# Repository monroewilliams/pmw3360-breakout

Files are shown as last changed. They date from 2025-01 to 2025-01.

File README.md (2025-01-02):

# Notes on this fork

I created this fork of jfedor2's excellent pmw3360-breakout board because I wanted a breakout that would better serve my particular needs.

Specifically, I wanted it to fit the existing plastics of [my trackball design](https://github.com/monroewilliams/trackball), which means having roughly the same dimensions and mounting hole locations as the ones I originally sourced from MrJohnK on Tindie [here](https://www.tindie.com/products/jkicklighter/pmw3360-motion-sensor/) (that one has been discontinued, but there are similar ones available from other sellers on Tindie).

Instead of the 2.54mm pitch pin header, also I wanted it to have a JST-SH (1.0mm pitch) connector with a regularized pinout based on [Pmod type 2](https://en.wikipedia.org/wiki/Pmod_Interface) so I can easily assemble it using compact off-the-shelf cables.

Since I don't need level-shifters (I'm using it with microcontrollers that already have compatible 3.3v logic), this breakout seemed like the perfect starting point. 

Any issues with the changes I made to this layout are solely my fault, so please don't bother jfedor2 with them. :) 

Original (pre-fork) readme follows:

# PMW3360 breakout board

The board doesn't do any level shifting so it only works with 3.3V logic.

The dimensions of the board are 22x34mm and the mounting holes are for M2 screws.

The files in the [fabrication](fabrication) folder can be used to order this board from JLCPCB with SMT assembly. The board you get includes everything except the actual sensor. If some of the specific components are out of stock, try to find an equivalent with the same package and parameters.

The sensor chip should be soldered on the top side (the side where all the other components are). The dot marks pin 1. The optic goes on the bottom side.

a render of the PCB

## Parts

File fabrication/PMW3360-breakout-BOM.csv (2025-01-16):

Designator | Comment | Footprint | DNP | LCSC
U2 | TLV70018DDCR | Package_TO_SOT_SMD:SOT-23-5 |  | C79924
R2 | 10k | Resistor_SMD:R_0603_1608Metric |  | C25804
R1 | 39 | Resistor_SMD:R_0603_1608Metric |  | C137733
J1 | Conn_01x06 | PMW3360:JST_SH_BM06B-SRSS-TB_1x06-1MP_P1.00mm_Vertical |  | C7430455
C3 | 4.7u | Capacitor_SMD:C_0603_1608Metric |  | C19666
C2 | 1u | Capacitor_SMD:C_0603_1608Metric |  | C15849
C1 | 0.1u | Capacitor_SMD:C_0603_1608Metric |  | C14663

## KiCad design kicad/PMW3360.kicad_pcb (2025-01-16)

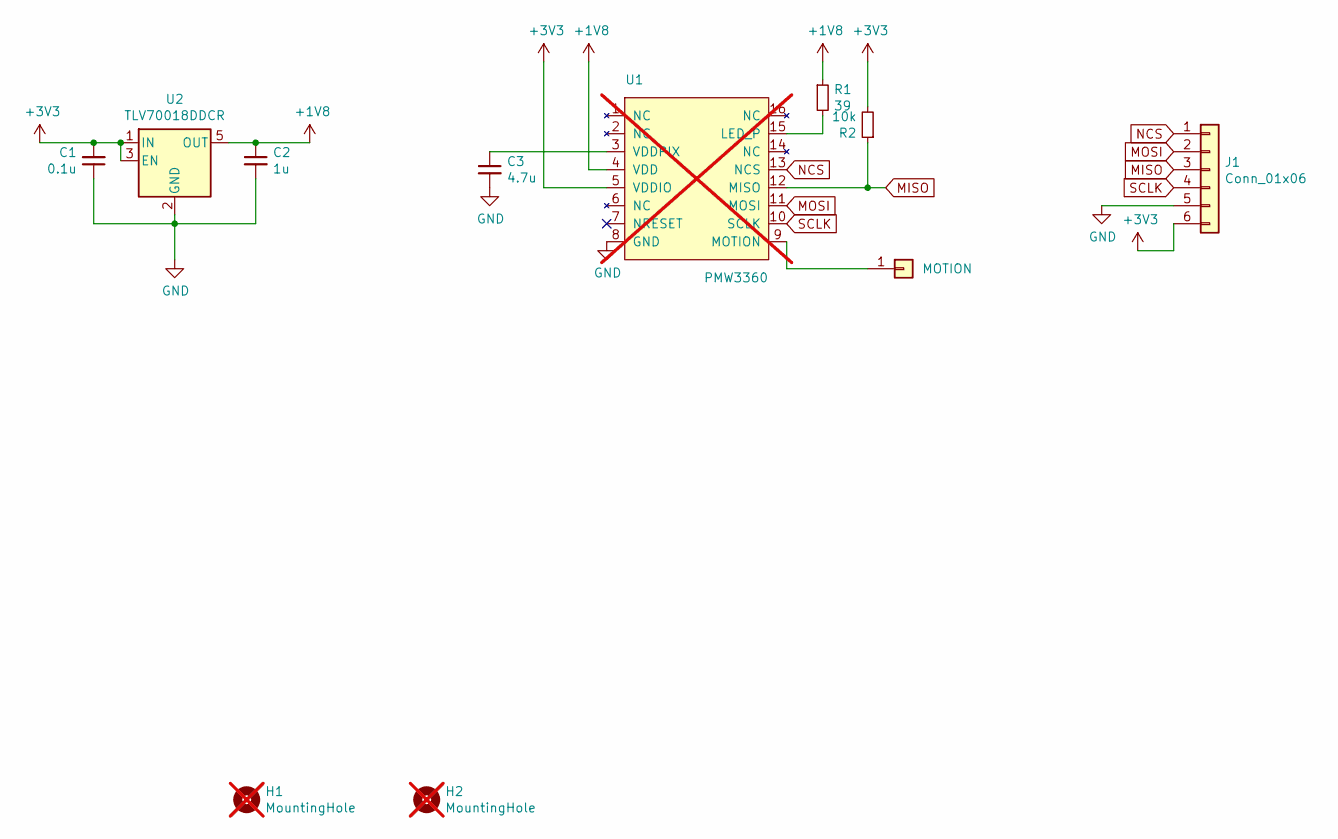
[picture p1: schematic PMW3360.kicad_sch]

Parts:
C1: 0.1u; C_0603_1608Metric; LCSC C14663
C2: 1u; C_0603_1608Metric; LCSC C15849
C3: 4.7u; C_0603_1608Metric; LCSC C19666
H1, H2: MountingHole; MountingHole_2.2mm_M2; not fitted
J1: Conn_01x06; JST_SH_BM06B-SRSS-TB_1x06-1MP_P1.00mm_Vertical; LCSC C7430455
J2: MOTION; PinSocket_1x01_P2.54mm_Vertical
R1: 39; R_0603_1608Metric; LCSC C137733
R2: 10k; R_0603_1608Metric; LCSC C25804
U1: PMW3360; not fitted
U2: TLV70018DDCR; SOT-23-5; LCSC C79924

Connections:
+1V8: C2.1, R1.1, U1.4 (VDD), U2.5 (OUT)
+3V3: C1.2, J1.6, R2.2, U1.5 (VDDIO), U2.1 (IN), U2.3 (EN)
GND: C1.1, C2.2, C3.2, J1.5, U1.8 (GND), U2.2 (GND)
MISO: J1.3, R2.1, U1.12 (MISO)
MOSI: J1.2, U1.11 (MOSI)
NCS: J1.1, U1.13 (NCS)
unnamed: J2.1, U1.9 (MOTION)
unnamed: R1.2, U1.15 (LED_P)
unnamed: C3.1, U1.3 (VDDPIX)
SCLK: J1.4, U1.10 (SCLK)

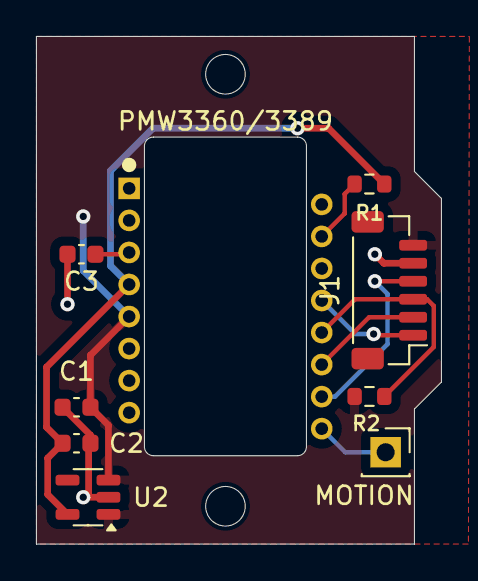
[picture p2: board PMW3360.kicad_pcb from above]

Board: 2 copper layers, 22.5 x 28.2 mm, 11 parts (0 on the bottom side), 10 nets.

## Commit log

2024-12-25 Modified the board dimensions and mounting hole locations to roughly match the old MrJohnK boards from Tindie (22x28mm, with two mounting holes) Changed the connector to a 6-pin JST SH 1.0mm pitch pl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
    [PMW3360-B_Cu.gbr, PMW3360-B_Mask.gbr, PMW3360-B_Paste.gbr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]
2024-12-26 Switched to JST_GH 1.25mm side-entry plug. Updated part info for the 1.8v regulator to the one that's actually available through JLCPCB.
    [PMW3360-B_Cu.gbr, PMW3360-B_Mask.gbr, PMW3360-B_Paste.gbr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]
2024-12-28 Change back to JST SH 1.0mm pitch connector Use top-side 3.3v fill zone for simpler routing add .gitignore file
    [PMW3360-B_Cu.gbr, PMW3360-B_Mask.gbr, PMW3360-B_Paste.gbr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]
2025-01-02 Update the readme for this fork. Add the url of this github repository to the rear silkscreen layer.
    [PMW3360-B_Cu.gbr, PMW3360-B_Mask.gbr, PMW3360-B_Paste.gbr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]
2025-01-16 Make more symmetrical. Clean up silkscreens a bit. Add a pad for the motion line.
    [PMW3360-B_Cu.gbr, PMW3360-B_Mask.gbr, PMW3360-B_Paste.gbr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]
